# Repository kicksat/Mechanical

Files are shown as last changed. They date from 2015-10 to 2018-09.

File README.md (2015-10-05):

# CAD Model of KickSat-2

These drawings can be viewed with the free [eDrawings Viewer](http://www.edrawingsviewer.com/ed/edrawings-viewer.htm) program if you don't have SolidWorks.

# License

[Creative Commons Attribution-ShareAlike 4.0 International](https://creativecommons.org/licenses/by-sa/4.0/)

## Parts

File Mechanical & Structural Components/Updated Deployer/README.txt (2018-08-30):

%%%%%%%%
% NOTE %
%%%%%%%%

[07-25-2018] These files still need to be validated against the physical model and updated with exact tolerancing.
[08-30-2018] Deployer Assembly has been validated with prototype. Small revisions made to GD&T, hole sizes and hole locations.

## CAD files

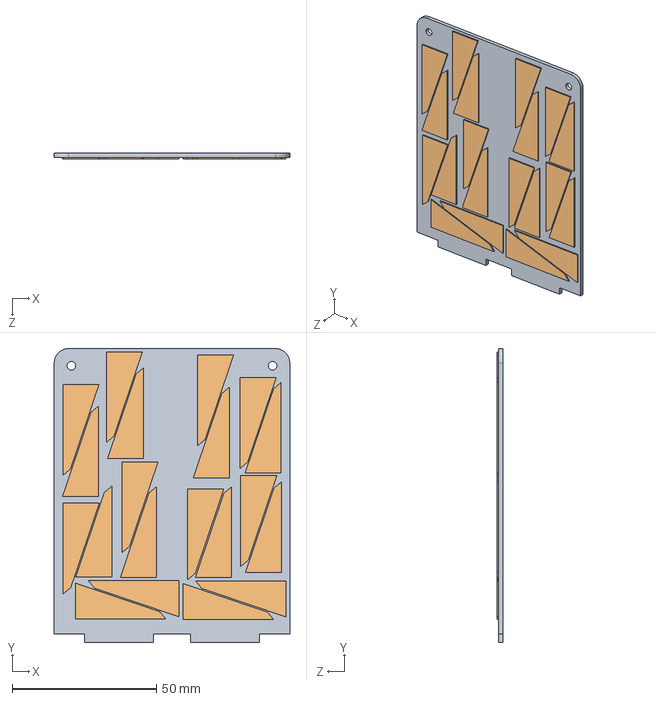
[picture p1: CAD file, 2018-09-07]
Avionics/Solar Panels/Side X Solar Panel Assembly.SLDASM
81.8 x 102.0 x 2.00 mm
Side X Solar Panel
Side X Solar Cells

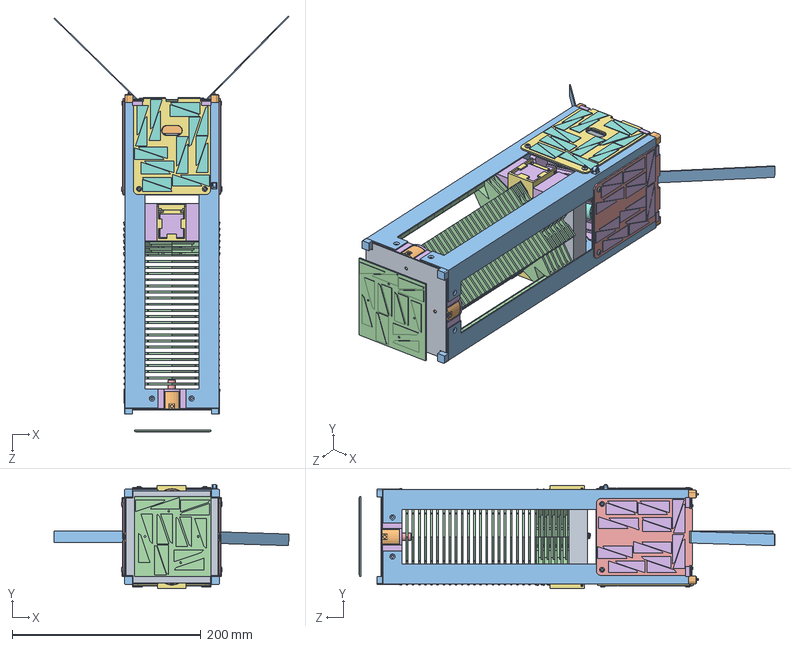
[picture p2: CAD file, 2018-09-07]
KickSat-2 Full Assembly With Updated Deployer.SLDASM
249.2 x 110.6 x 441.3 mm
M2x5 Screw x 4
Rails x 4
Outershell
3dppart2 x 15
3dprintpart
BottomAntennaAttach1
Base x 2
BottomAntennaAttach2
GPSHolder
PCB
molex 53261 x 3
FTSH-50-D
T-1S15 x 10
Micro USB
Can BMI-S-208-F
Lid BMI-S-208-F
Patch Ant GP.1575.25.4.A.02
Molex SMA 73251-1150
Led 0603 x 2
Button B3U-1000P
SMA Right Angle
GPS Antenna x 2
Slider x 2
5pinConnector
CircuitBoardPart
Connector1 x 2
RollerDeployerSwitch
Top Solar Panel
Bolt,8mm_x_24.6mm
DeployerBase
TopClasp
BottomClasp
CoverPlate
RetentionPlate
M103 Battery Plate x 2
single battery holder x 8
battery pack cap x 2
Battery, 18650_LGABC11865_3.7V x 6
grommet, 1-8in ID, 5269T211 x 2
screw, pan head, 0-80, 1_8L, 316SS, 91400A030 x 32
nut, 0-80, standard, 18-8SS, 91841A115 x 32
Sprites x 102
Side X Solar Panel x 2
Side X Solar Cells x 2
Side Y Solar Panel x 2
Side Y Solar Cells x 2
Pan Head Screw M3X6 x 8
Skel Baseplate, Dual-Switch Assy
Antenna_Main x 2
Antenna Board
Antenna_Short x 2
Solar Panel Clips x 4
M2x5 Screw Button Head x 4

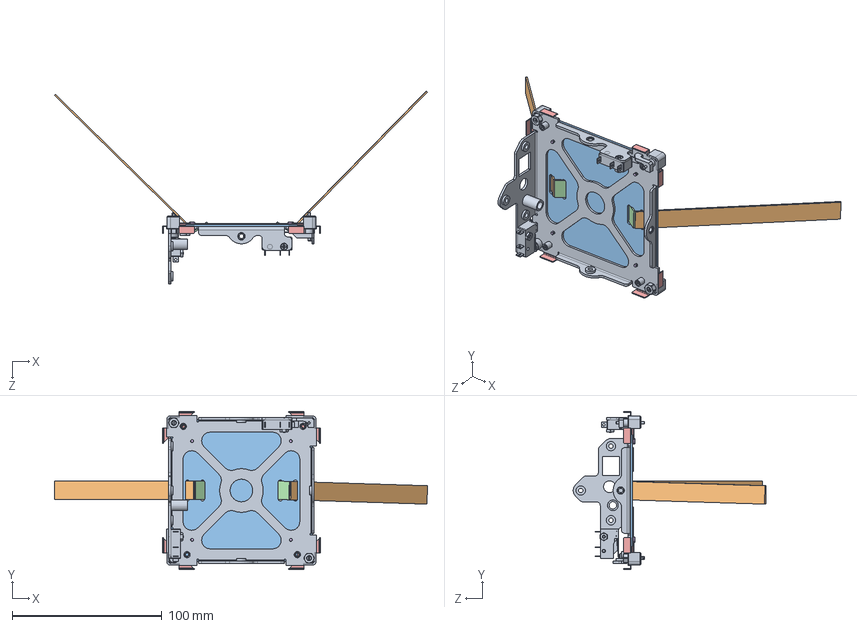
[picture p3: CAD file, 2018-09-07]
Mechanical & Structural Components/Bottom/Base Solar Panel Installation.SLDASM
249.2 x 105.6 x 128.7 mm
Skel Baseplate, Dual-Switch Assy
Antenna_Main x 2
Antenna Board
Antenna_Short x 2
Solar Panel Clips x 4
M2x5 Screw Button Head x 4

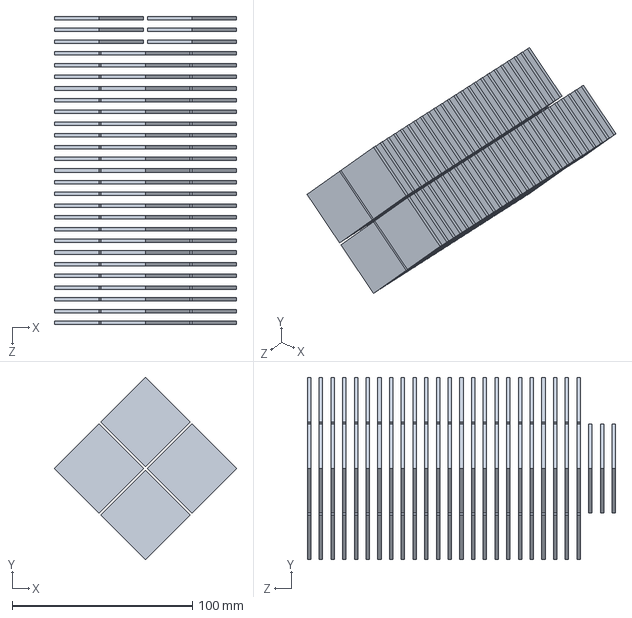
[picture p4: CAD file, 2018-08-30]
Mechanical & Structural Components/Sprite Deployer/Sprite Installation.SLDASM
101.0 x 101.0 x 171.0 mm
Sprites x 102

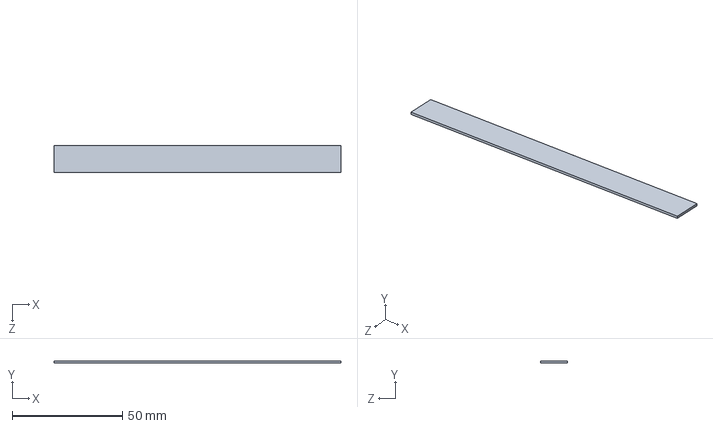
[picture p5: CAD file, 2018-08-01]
Avionics/Main Antenna/Antenna_Main.SLDPRT
130.0 x 1.00 x 12.3 mm

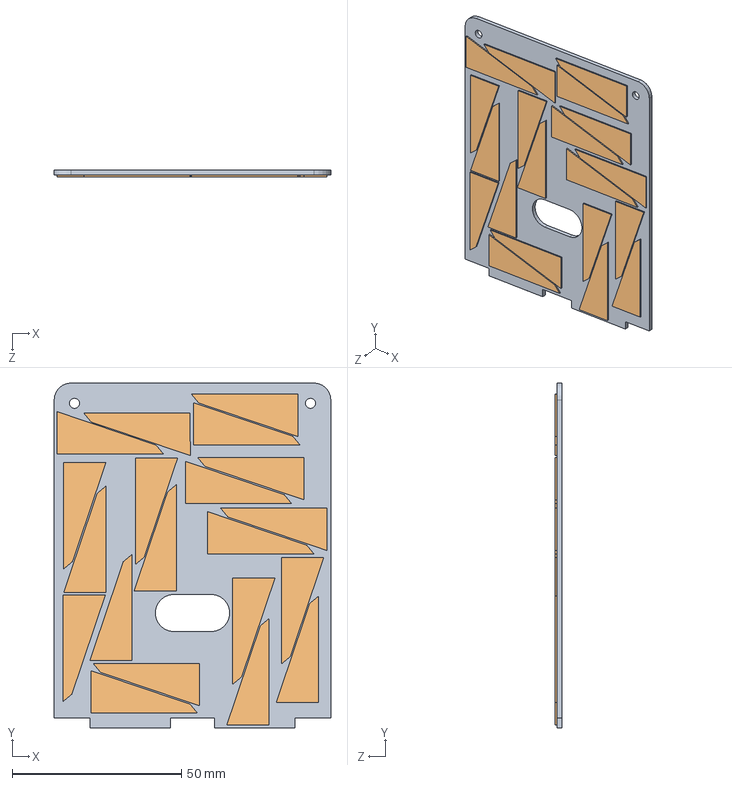
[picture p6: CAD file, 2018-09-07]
Avionics/Solar Panels/Side Y Solar Panel Assembly.SLDASM
81.8 x 102.0 x 2.00 mm
Side Y Solar Panel
Side Y Solar Cells

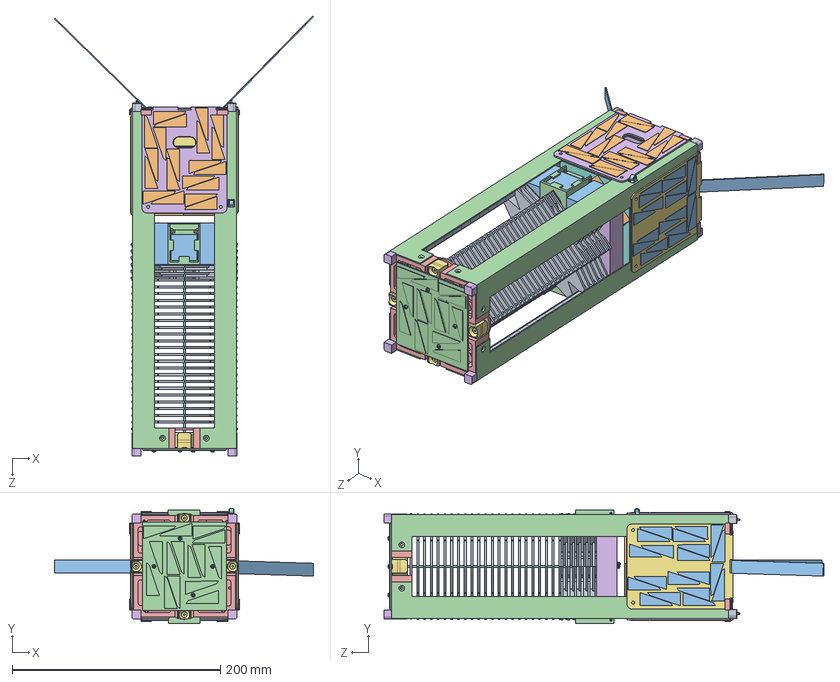
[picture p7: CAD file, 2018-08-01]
KickSat-2 Full Assembly.SLDASM
249.2 x 110.6 x 422.9 mm
Skel Baseplate, Dual-Switch Assy
M2x5 Screw x 4
Rails x 4
Outershell
Top
Leg(Top) x 4
DeployerPiece#1_v5
CarbonFiberRodX x 4
3dppart2 x 15
3dprintpart
BottomAntennaAttach1
Base x 2
BottomAntennaAttach2
GPSHolder
PCB
molex 53261 x 3
FTSH-50-D
T-1S15 x 10
Micro USB
Can BMI-S-208-F
Lid BMI-S-208-F
Patch Ant GP.1575.25.4.A.02
Molex SMA 73251-1150
Led 0603 x 2
Button B3U-1000P
SMA Right Angle x 4
GPS Antenna x 2
Slider x 2
5pinConnector
CircuitBoardPart
Connector1 x 2
Antenna Splitter Holder x 2
Batter Pack x 2
Antenna Splitter
Antenna_Main x 2
Antenna Board
Antenna_Short x 2
Side Y Solar Panel x 2
Side X Solar Panel x 2
RollerDeployerSwitch
Sprites x 102
Side Y Solar Cells x 2
Side X Solar Cells x 2
Top Solar Panel
Solar Panel Clips x 4
M2x5 Screw Button Head x 8

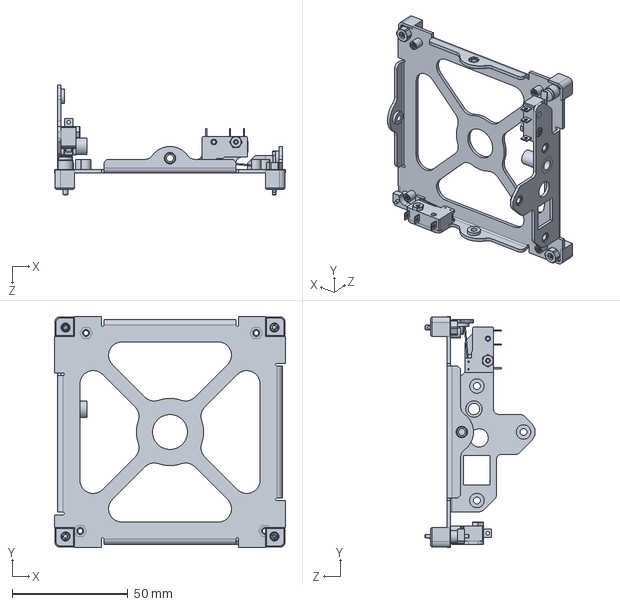
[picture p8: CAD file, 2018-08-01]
Mechanical & Structural Components/Bottom/Skel Baseplate, Dual-Switch Assy.SLDPRT
100.0 x 100.0 x 47.8 mm

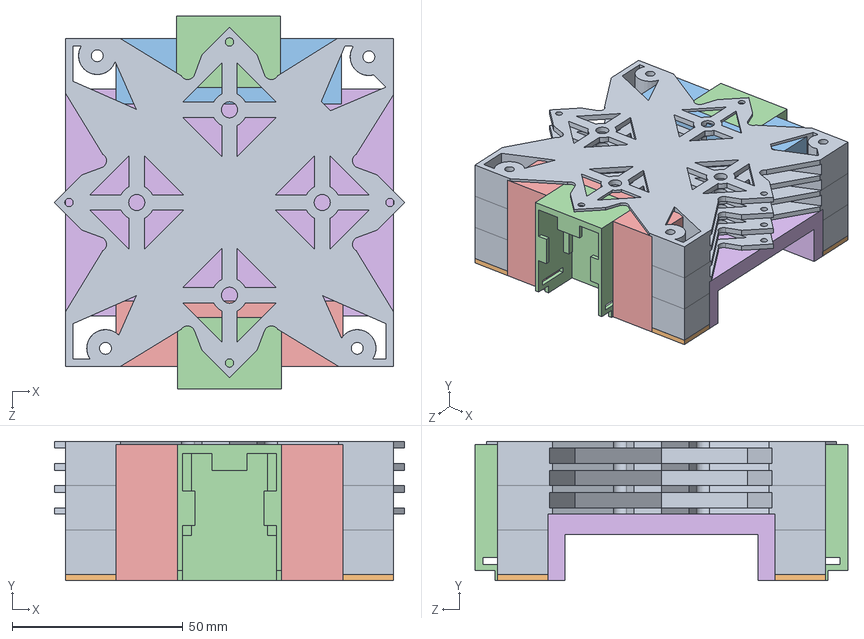
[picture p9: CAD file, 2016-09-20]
Mechanical & Structural Components/Sprite Housing/BottomStart.SLDASM
102.6 x 40.9 x 109.2 mm
3dppart2 x 3
3dprintpart
BottomAntennaAttach1
Base x 2
BottomAntennaAttach2
GPSHolder

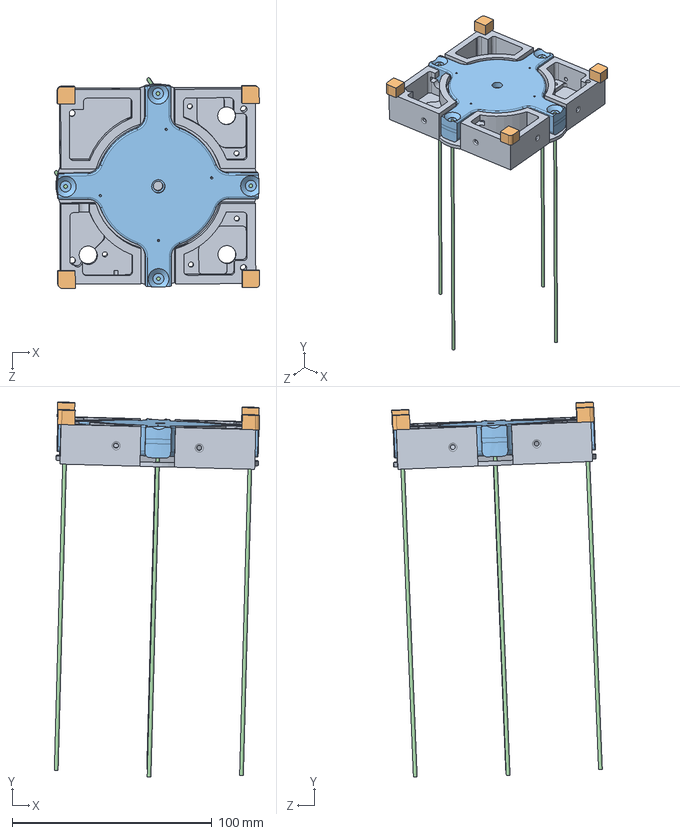
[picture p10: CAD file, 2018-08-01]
Mechanical & Structural Components/Top and Deployer/Complete Deployer Assembly.SLDASM
102.9 x 187.9 x 105.6 mm
Top
Leg(Top) x 4
DeployerPiece#1_v5
CarbonFiberRodX x 4

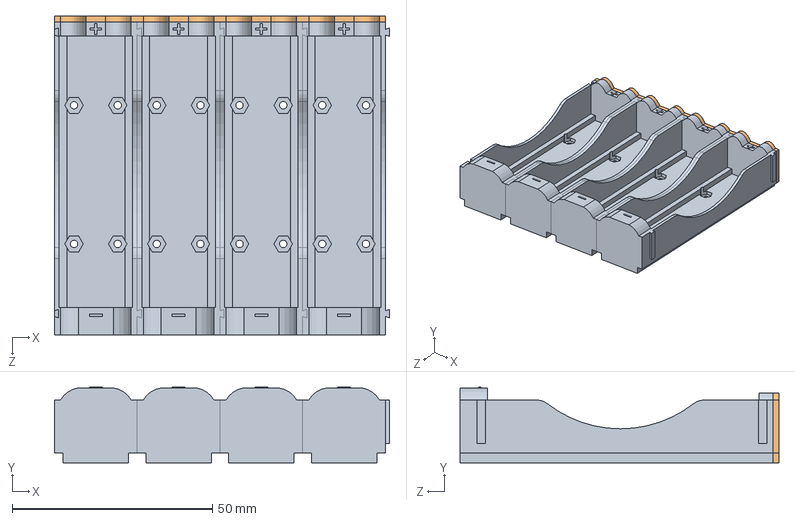
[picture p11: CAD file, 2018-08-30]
Avionics/Batteries/M102 Battery Holder Assembly.SLDASM
83.6 x 18.9 x 79.5 mm
single battery holder x 4
battery pack cap

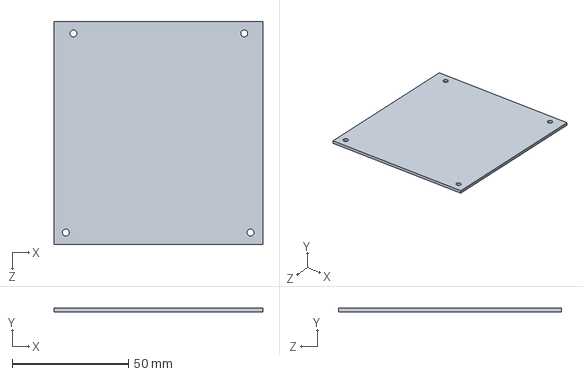
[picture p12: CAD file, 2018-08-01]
Avionics/Flight Computer and Radio Board/CBA1.SLDASM
90.0 x 1.60 x 95.9 mm

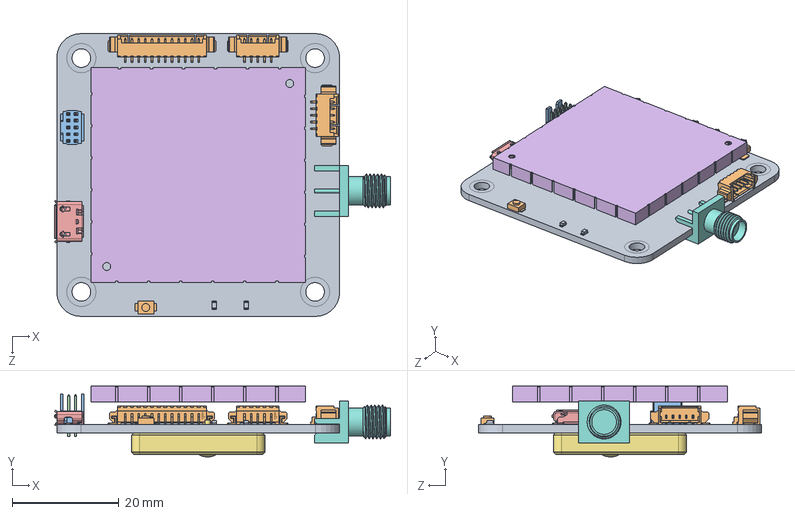
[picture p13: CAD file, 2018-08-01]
Avionics/GPS/swiftnav_v2_3.SLDASM
63.0 x 13.3 x 53.0 mm
PCB
molex 53261 x 3
FTSH-50-D
T-1S15 x 10
Micro USB
Lid BMI-S-208-F
Patch Ant GP.1575.25.4.A.02
Molex SMA 73251-1150
Led 0603 x 2
Button B3U-1000P

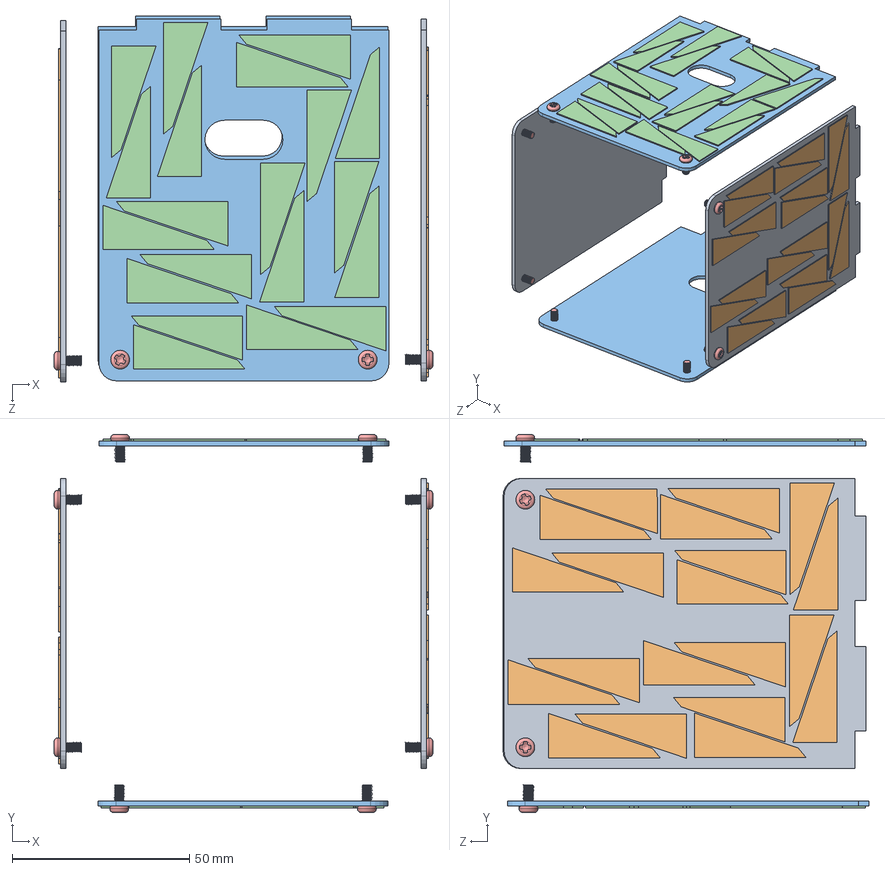
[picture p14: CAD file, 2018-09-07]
Avionics/Solar Panels/Side Solar Panel Installation.SLDASM
106.8 x 106.6 x 103.2 mm
Side X Solar Panel x 2
Side X Solar Cells x 2
Side Y Solar Panel x 2
Side Y Solar Cells x 2
Pan Head Screw M3X6 x 8

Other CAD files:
Avionics/Antenna Splitter/Antenna Splitter Assembly.SLDASM
KickSat-2 Full Assembly (Marc Choueiri's conflicted copy 2015-09-20).SLDASM
Mechanical & Structural Components/Sprite Housing/Sprite Deployer.SLDASM
Avionics/Flight Computer and Radio Board/Radio Board.SLDASM
Avionics/Antenna Splitter/Antenna Splitter Holder.SLDPRT
Avionics/Antenna Splitter/Antenna Splitter.SLDPRT
Avionics/Antenna Splitter/Power Divider Holder.SLDDRW
Avionics/Antenna Splitter/SMA Right Angle.SLDPRT
Avionics/Batteries/Batter Pack.SLDPRT
Avionics/Batteries/Battery Assembly.SLDASM
Avionics/Batteries/Battery Holder.SLDPRT
Avionics/Batteries/Battery, 18650_LGABC11865_3.7V.sldprt
Avionics/Batteries/M100 Battery Assembly.SLDASM
Avionics/Batteries/M101 Battery Assembly.SLDASM
Avionics/Batteries/M103 Battery Plate.SLDPRT
Avionics/Batteries/SCOTCH WELD EC2216.SLDPRT
Avionics/Batteries/battery pack cap.sldprt
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

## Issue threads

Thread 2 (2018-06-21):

Burn wire debugging + mechanical design

zacmanchester, 2018-06-21:

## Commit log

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2015-09-21 Shrunk deployer side switch hole on Outhershell
    [Outershell.SLDPRT]
2015-09-25 Installed new top solar panel and antenna board
    [Antenna Assembly.SLDASM, Antenna Board 2.SLDPRT, KickSat-2 Full Assembly.SLDASM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]
2015-09-25 Installed new solar panel top and antenna board
    [KickSat-2 Full Assembly.SLDASM]
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2015-10-19 Fixed rail holes size in deployer and solar cells on top deployer
    Fixed rail holes size in deployer and solar cells on top deployer
    [3dppart2.SLDPRT, 3dprintpart.SLDPRT, BottomStart.SLDASM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]
2015-10-19 Made rail holes bigger to 4mm
    [3dppart2.SLDPRT, 3dprintpart.SLDPRT, BottomStart.SLDASM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]
2015-10-20 Edits to Sprite Deployer for Printing, STL files are for printing
    Edits to Sprite Deployer for Printing. STL files "Sprite Deployer" and
    "BottomStart" are for printing because printing them together would be
    $500+ and would require more bureaucratic BS
    [Base.SLDPRT, BottomStart.SLDASM, BottomStart.STL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]
2015-11-02 Edit to Sprites and moved to proper locations, editing deployer locally
    [KickSat-2 Full Assembly.SLDASM, Sprites.SLDPRT]
2015-11-03 Edit to walls of sprite deployer to fit sprites
    [3dppart2.SLDPRT, BottomStart.SLDASM, KickSat-2 Full Assembly.SLDASM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]
2015-11-03 Complete changes to sprite deployer
    [3dppart2.SLDPRT, BottomStart.SLDASM, KickSat-2 Full Assembly.SLDASM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]
2015-11-03 Printable changes made to deployer and saved in STL files
    [3dppart2.SLDPRT, BottomStart.SLDASM, BottomStart.STL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]
2015-11-03 Same as last group of changes
    [BottomStart.SLDASM, BottomStart.STL, KickSat-2 Full Assembly.SLDASM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]
2015-11-13 Added all missing screws
    [KickSat-2 Full Assembly.SLDASM, M3 PEM Nuts.SLDPRT, M3 pan Head x 10mm.SLDPRT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]
2015-11-24 Changes to Sprite Deployer Length and Width
    Decreased LxW from 97.6x97.6mm to 96.1x96.1mm. Made all appropirate
    changes to mate
    [3dppart2.SLDPRT, 3dprintpart.SLDPRT, BottomAntennaAttach1.SLDPRT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]
2015-11-24 Roller switch moved to proper postion
    [KickSat-2 Full Assembly.SLDASM, Outershell.SLDPRT]
2015-11-24 Changes to Carbon Fiber Rod Holes of Deployer
    Changed to appropriate location after measured with calipers and
    calculated in excel. Appropriate mates made as well
    [3dppart2.SLDPRT, BottomStart.SLDASM, KickSat-2 Full Assembly.SLDASM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]
2015-12-02 Addition of Hex Screws to Top Deployer
    [Antenna Splitter Assembly.SLDASM, Antenna Splitter Holder.SLDPRT, BMI-S-208-F.SLDASM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]
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2015-12-07 GPS Receiver Moved and Bottom Deployer Side Walls Added
    [BottomStart.SLDASM, GPSHolder.SLDPRT, Sprite Deployer.SLDASM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]
2015-12-07 Final Changes to Deployer
    Added walls for GPS, thinner walls for sprite levels
    [3dppart2 - Copy.SLDPRT, 3dppart2.SLDPRT, 3dprintpart.SLDPRT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]
2015-12-07 FINAL (actually this time) Changes to Sprite Deployer
    Carbon fiber rod holes diameter increased from 2.4 to 2.75, odd hole was
    moved .5mm further out to align with aluminum plate
    [3dppart2.SLDPRT, BottomStart.SLDASM, Deployer Top Part 2.SLDPRT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]
2016-01-28 Walls changed to 2 segments for test print
    [3dpart2.STL, 3dppart2.SLDPRT]
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2016-02-05 Final Changes to Sprite Housing, Just Send to RPL for Printing Full Housing
    [3dppart2.SLDPRT, BottomStart.SLDASM, KickSat-2 Full Assembly.SLDASM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]
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2016-07-24 Changes to Deployer Piece to Accommodate Spring
    [DeployerPiece#1_v5.SLDPRT, DeployerPiece#1_v5.STL]
2016-07-28 Increased depth of center hole to allow spring to go further into deployer piece
    [Complete Deployer Assembly.SLDASM, DeployerPiece#1_v5.SLDPRT, DeployerPiece#1_v5.STL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]
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2016-08-29 Changed one file name, and small change to deployer piece
    I realized the support for hole for the through screw was to thin for
    comfort so I added some more. This was because I decreased the thickness
    to make room for the new spring
    [3dpart2.STL, 3dppart2 - Copy.SLDPRT, 3dppart2.SLDPRT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]
2016-09-20 Added thickness to end b/c helicoils were pushing out walls
    [BottomStart.SLDASM, Complete Deployer Assembly.SLDASM, DeployerPiece#1_v5.SLDPRT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]
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2016-10-16 New G-Code for Deployer Print
    [DeployerPiece#1_v5.SLDPRT, DeployerPiece#1_v5.STL]
2016-11-20 Enlarging GPS patch antenna slider to be snug with wall
    [Slider.SLDPRT, Slider.STL]
2018-07-17 Updated CAD models to current version
    Updated CAD models to reflect changes made and to make the assembly load without errors
    [3dppart2.SLDPRT, 3dprintpart.SLDPRT, 5pinConnector.SLDPRT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]
2018-07-20 Uploaded SketchUp file of updated deployer
    [deployer.skp]
2018-07-25 Converted updated deployer from Sketchup to SW2017
    Converted Sketchup model into a Solidworks 2017 assembly. Note: tolerances are not exact and need to be updated to match hardware.
    [BlockPiece.SLDPRT, Bolt,8mm_x_24.6mm.SLDPRT, Box.SLDPRT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]
2018-07-31 Fixed erroneous issues with parts for assembly
    Fixed misaligned holes in the clip parts and inner deployer interface
    Realigned holes in the outer box and inner deployer interface to better align with the carbon rods in the full assembly
    Fixed missing cuts in the top plate
    Packaged assembly view better
    [BoxTry2.SLDPRT, Clip1.SLDPRT, Clip2.SLDPRT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]
2018-08-01 Updated full assembly with updated deployer assembly
    Nearly completed full assembly version uses the new deployer. Note that external references are used to ensure that alignment is accurate for each part. Note that top solar panel plate is not mated t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
    For some reason GitHub wants to update every other file as well despite me not touching them.
    Not the final version!!!
    (note to self: add in carbon rods from initial deployer assembly)
    [3dppart2.SLDPRT, 3dprintpart.SLDPRT, 5pinConnector.SLDPRT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]
2018-08-02 Add files via upload
    Modification to deployer clasp design and other hole alignment fixes.
    [BoxTry2.SLDPRT, Clip1.SLDPRT, Clip2v2.SLDPRT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]
2018-08-05 Deployer Assembly Fixes
    Various tweaks to hole locations and dimensioning on Deployer Assy.
    [Body1.sldprt, BottomClasp.SLDPRT, CoverPlate.SLDPRT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]
2018-08-05 Unused Part
    Block Piece not used in current assembly
    [BlockPiece.SLDPRT]
2018-08-05 Delete Clip1.SLDPRT
    Redundant CAD file.
    [Clip1.SLDPRT]
2018-08-05 Delete Clip2.SLDPRT
    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
    [Clip2.SLDPRT]
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2018-08-09 Extrusion Cut Fix to Deployer Retention Plate
    [KickSat-2 Full Assembly With Updated Deployer.SLDASM, RetentionPlate.SLDPRT, UpdatedDeployerAssemblyV2.SLDASM]
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2018-08-30 Battery Pack Update
    Replaced old battery model with full assemblies of the 4-pk and 2-pk LiPo batteries.
    [Battery, 18650_LGABC11865_3.7V.sldprt, M100 Battery Assembly.SLDASM, M101 Battery Assembly.SLDASM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]
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2018-09-04 Deployer Fastener & Material Update
    Created new parts: FenderWasher, TeeNut
    Added deployer base material: Al 5052-H32
    Suppressed outdated fasteners
    Hid several hex nuts
    [Body1.sldprt, DeployerBase.SLDPRT, FenderWasher.SLDPRT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]
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
